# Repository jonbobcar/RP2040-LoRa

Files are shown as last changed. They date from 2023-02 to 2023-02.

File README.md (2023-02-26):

# RP2040 LoRa
 RP2040 based board with a LoRa radio

KiCad files are made with KiCad v7.

Care should be used when purchasing BMS to choose one that will auto-start. There are SKUs of this BMS that will only start if external power is provided and then removed. I have chosen AP9101CAK6-ANTRG1, which is an auto-start version.

This board is mostly tested. Files on `main` should be used with caution, you may need to do some debugging.

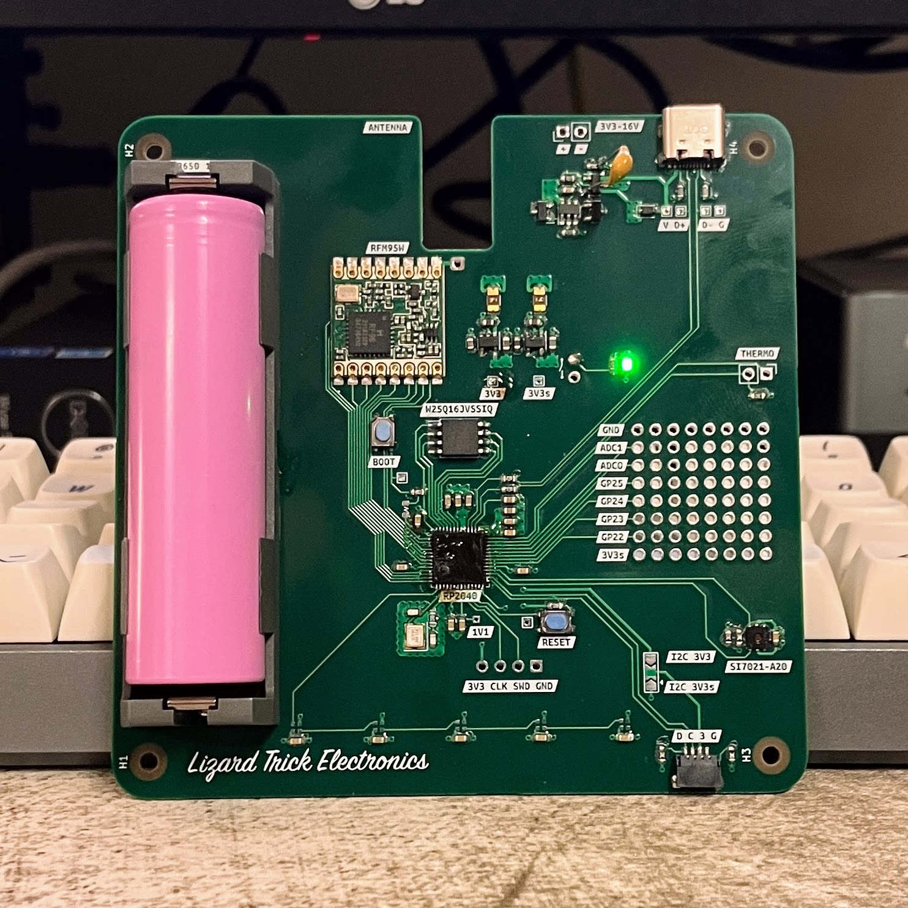
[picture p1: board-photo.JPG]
Photo of the board


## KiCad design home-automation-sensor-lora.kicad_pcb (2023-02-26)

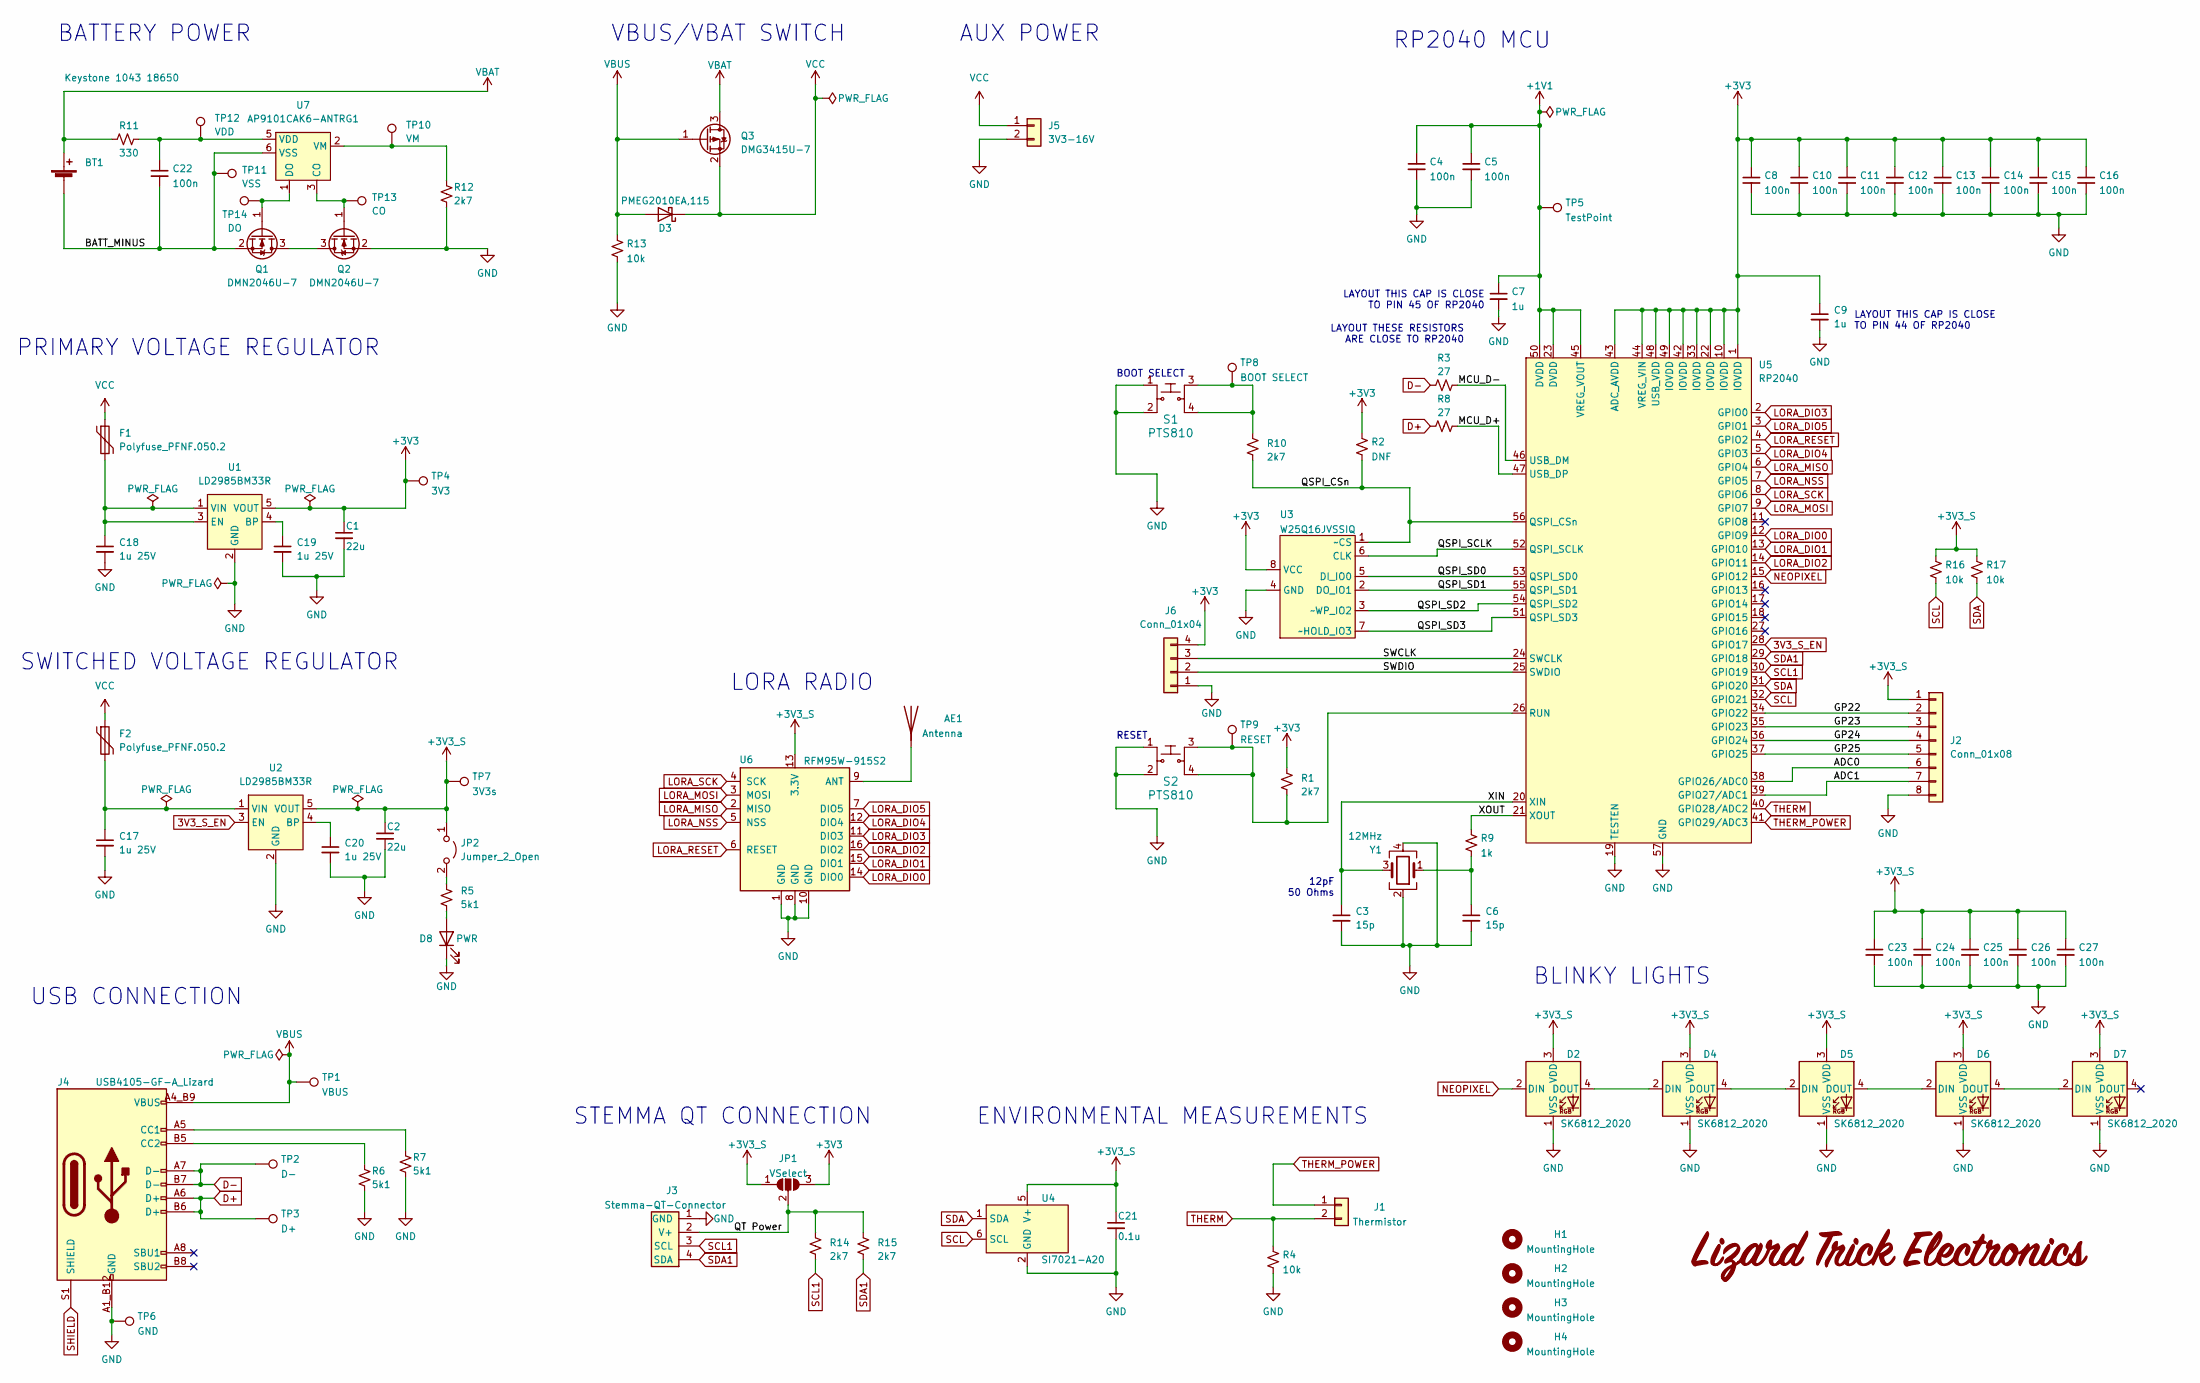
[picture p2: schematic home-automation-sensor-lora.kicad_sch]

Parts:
AE1: Antenna; Spring_Antenna_1.0_Drill
BT1: Keystone 1043 18650
C1, C2: 22u; C_0603_Lizard
C3, C6: 15p; C_0603_Lizard
C4, C5, C8, C10, C11, C12, C13, C14, C15, C16, C22, C23, C24, C25, C26, C27: 100n; C_0603_Lizard
C7, C9: 1u; C_0603_Lizard
C17, C18, C19, C20: 1u 25V; C_0603_Lizard
C21: 0.1u; C_0603_Lizard
D2, D4, D5, D6, D7: SK6812_2020; SK6812 2020
D3: PMEG2010EA,115; D_SOD-323
D8: PWR; LED-0805-Lizard
F1, F2: Polyfuse_PFNF.050.2; R_1206_3216Metric
G1: LOGO; Lizard Text Logo
H1, H2, H3, H4: MountingHole; Lizard_MountingHole_3.5mm
J1: Thermistor; PinHeader_1x02_P2.54mm_Vertical
J2: Conn_01x08; Prototype Area 8x8
J3: Stemma-QT-Connector; STEMMA-QT-CONNECTOR
J4: USB4105-GF-A_Lizard; GCT_USB4105-GF-A
J5: 3V3-16V; PinHeader_1x02_P2.54mm_Vertical
J6: Conn_01x04; PinHeader_1x04_P2.54mm_Vertical
JP1: VSelect; SolderJumper-3_P2.0mm_Open_TrianglePad1.0x1.5mm
JP2: Jumper_2_Open; Pin Jumper lizard
Q1, Q2: DMN2046U-7; SOT-23
Q3: DMG3415U-7; SOT-23
R1, R10, R12, R14, R15: 2k7; R_0603_Lizard
R2: DNF; R_0603_Lizard
R3, R8: 27; R_0603_Lizard
R4, R13, R16, R17: 10k; R_0603_Lizard
R5, R6, R7: 5k1; R_0603_Lizard
R9: 1k; R_0603_Lizard
R11: 330; R_0603_Lizard
S1, S2: PTS810; PTS_180_Tactile_Switch
TP1: VBUS; TestPoint_THTPad_1.0x1.0mm_Drill0.5mm
TP2: D-; TestPoint_THTPad_1.0x1.0mm_Drill0.5mm
TP3: D+; TestPoint_THTPad_1.0x1.0mm_Drill0.5mm
TP4: 3V3; TestPoint_THTPad_1.0x1.0mm_Drill0.5mm
TP5: TestPoint; TestPoint_THTPad_1.0x1.0mm_Drill0.5mm
TP6: GND; TestPoint_THTPad_1.0x1.0mm_Drill0.5mm
TP7: 3V3s; TestPoint_THTPad_1.0x1.0mm_Drill0.5mm
TP8: BOOT SELECT; TestPoint_THTPad_1.0x1.0mm_Drill0.5mm
TP9: RESET; TestPoint_THTPad_1.0x1.0mm_Drill0.5mm
TP10: VM; TestPoint_THTPad_1.0x1.0mm_Drill0.5mm-Lizard
TP11: VSS; TestPoint_THTPad_1.0x1.0mm_Drill0.5mm-Lizard
TP12: VDD; TestPoint_THTPad_1.0x1.0mm_Drill0.5mm-Lizard
TP13: CO; TestPoint_THTPad_1.0x1.0mm_Drill0.5mm-Lizard
TP14: DO; TestPoint_THTPad_1.0x1.0mm_Drill0.5mm-Lizard
U1, U2: LD2985BM33R; SOT-23-5
U3: W25Q16JVSSIQ; SOIC-8_5.275x5.275mm_P1.27mm
U4: SI7021-A20
U5: RP2040; RP2040_QFN-56
U6: RFM95W-915S2; XCVR_RFM95W-915S2
U7: AP9101CAK6-ANTRG1; SOT-23-6
Y1: 12MHz; Crystal_SMD_3225-4Pin_3.2x2.5mm

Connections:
3V3_S_EN: U2.3 (EN), U5.28 (GPIO17)
+1V1: C4.1, C5.1, C7.1, TP5.1, U5.23 (DVDD), U5.45 (VREG_VOUT), U5.50 (DVDD)
+3V3: C1.1, C8.1, C9.1, C10.1, C11.1, C12.1, C13.1, C14.1, C15.1, C16.1, J6.4, JP1.3 (B), R1.1, R2.1, TP4.1, U1.5 (VOUT), U3.8 (VCC), U5.1 (IOVDD), U5.10 (IOVDD), U5.22 (IOVDD), U5.33 (IOVDD), U5.42 (IOVDD), U5.43 (ADC_AVDD), U5.44 (VREG_VIN), U5.48 (USB_VDD), U5.49 (IOVDD)
+3V3_S: C2.1, C21.1, C23.1, C24.1, C25.1, C26.1, C27.1, D2.3 (VDD), D4.3 (VDD), D5.3 (VDD), D6.3 (VDD), D7.3 (VDD), J2.1, JP1.1 (A), JP2.1 (A), R16.1, R17.1, TP7.1, U2.5 (VOUT), U4.5 (V+), U6.13 (3.3V)
/ADC0: J2.6, U5.38 (GPIO26/ADC0)
/ADC1: J2.7, U5.39 (GPIO27/ADC1)
/BATT_MINUS: BT1.1 (-), C22.2, Q1.2 (S), TP11.1, U7.6 (VSS)
/GP22: J2.2, U5.34 (GPIO22)
/GP23: J2.3, U5.35 (GPIO23)
/GP24: J2.4, U5.36 (GPIO24)
/GP25: J2.5, U5.37 (GPIO25)
/MCU_D+: R8.2, U5.47 (USB_DP)
/MCU_D-: R3.2, U5.46 (USB_DM)
/QSPI_CSn: R2.2, R10.2, U3.1 (~CS), U5.56 (QSPI_CSn)
/QSPI_SCLK: U3.6 (CLK), U5.52 (QSPI_SCLK)
/QSPI_SD0: U3.5 (DI_IO0), U5.53 (QSPI_SD0)
/QSPI_SD1: U3.2 (DO_IO1), U5.55 (QSPI_SD1)
/QSPI_SD2: U3.3 (~WP_IO2), U5.54 (QSPI_SD2)
/QSPI_SD3: U3.7 (~HOLD_IO3), U5.51 (QSPI_SD3)
/QT Power: J3.2 (V+), JP1.2 (C), R14.1, R15.1
/SWCLK: J6.3, U5.24 (SWCLK)
/SWDIO: J6.2, U5.25 (SWDIO)
/XIN: C3.1, U5.20 (XIN), Y1.3
/XOUT: R9.1, U5.21 (XOUT)
D+: J4.A6 (D+), J4.B6 (D+), R8.1, TP3.1
D-: J4.A7 (D-), J4.B7 (D-), R3.1, TP2.1
GND: C1.2, C2.2, C3.2, C4.2, C5.2, C6.2, C7.2, C8.2, C9.2, C10.2, C11.2, C12.2, C13.2, C14.2, C15.2, C16.2, C17.2, C18.2, C19.2, C20.2, C21.2, C23.2, C24.2, C25.2, C26.2, C27.2, D2.1 (VSS), D4.1 (VSS), D5.1 (VSS), D6.1 (VSS), D7.1 (VSS), D8.1 (K), J2.8, J3.1 (GND), J4.A1_B12 (GND), J4.B1_A12 (GND), J5.2, J6.1, Q2.2 (S), R4.2, R6.2, R7.2, R12.2, R13.2, S1.1, S1.2, S2.1, S2.2, TP6.1, U1.2 (GND), U2.2 (GND), U3.4 (GND), U4.2 (GND), U5.19 (TESTEN), U5.57 (GND), U6.1 (GND), U6.8 (GND), U6.10 (GND), Y1.2, Y1.4
LORA_DIO0: U5.12 (GPIO9), U6.14 (DIO0)
LORA_DIO1: U5.13 (GPIO10), U6.15 (DIO1)
LORA_DIO2: U5.14 (GPIO11), U6.16 (DIO2)
LORA_DIO3: U5.2 (GPIO0), U6.11 (DIO3)
LORA_DIO4: U5.5 (GPIO3), U6.12 (DIO4)
LORA_DIO5: U5.3 (GPIO1), U6.7 (DIO5)
LORA_MISO: U5.6 (GPIO4), U6.2 (MISO)
LORA_MOSI: U5.9 (GPIO7), U6.3 (MOSI)
LORA_NSS: U5.7 (GPIO5), U6.5 (NSS)
LORA_RESET: U5.4 (GPIO2), U6.6 (RESET)
LORA_SCK: U5.8 (GPIO6), U6.4 (SCK)
NEOPIXEL: D2.2 (DIN), U5.15 (GPIO12)
unnamed: AE1.1 (A), U6.9 (ANT)
unnamed: C6.1, R9.2, Y1.1
unnamed: D2.4 (DOUT), D4.2 (DIN)
unnamed: D4.4 (DOUT), D5.2 (DIN)
unnamed: D5.4 (DOUT), D6.2 (DIN)
unnamed: D6.4 (DOUT), D7.2 (DIN)
unnamed: D8.2 (A), R5.2
unnamed: J4.A5 (CC1), R7.1
unnamed: J4.B5 (CC2), R6.1
unnamed: JP2.2 (B), R5.1
unnamed: Q1.3 (D), Q2.3 (D)
unnamed: Q1.1 (G), TP14.1, U7.1 (DO)
unnamed: Q2.1 (G), TP13.1, U7.3 (CO)
unnamed: R10.1, S1.3, S1.4, TP8.1
unnamed: C19.1, U1.4 (BP)
unnamed: C18.1, F1.2, U1.1 (VIN), U1.3 (EN)
unnamed: C20.1, U2.4 (BP)
unnamed: C17.1, F2.2, U2.1 (VIN)
unnamed: R1.2, S2.3, S2.4, TP9.1, U5.26 (RUN)
unnamed: C22.1, R11.1, TP12.1, U7.5 (VDD)
unnamed: R12.1, TP10.1, U7.2 (VM)
SCL: R16.2, U4.6 (SCL), U5.32 (GPIO21)
SCL1: J3.3 (SCL), R14.2, U5.30 (GPIO19)
SDA: R17.2, U4.1 (SDA), U5.31 (GPIO20)
SDA1: J3.4 (SDA), R15.2, U5.29 (GPIO18)
SHIELD: J4.S1 (SHIELD)
THERM: J1.2, R4.1, U5.40 (GPIO28/ADC2)
THERM_POWER: J1.1, U5.41 (GPIO29/ADC3)
VBUS: D3.2 (A), J4.A4_B9 (VBUS), J4.B4_A9 (VBUS), Q3.1 (G), R13.1, TP1.1
VCC: D3.1 (K), F1.1, F2.1, J5.1, Q3.2 (S)
VDD: BT1.2 (+), Q3.3 (D), R11.2

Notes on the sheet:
STEMMA QT CONNECTION
RESET
RP2040 MCU
LAYOUT THIS CAP IS CLOSE TO PIN 44 OF RP2040
12pF 50 Ohms
USB CONNECTION
LORA RADIO
AUX POWER
SWITCHED VOLTAGE REGULATOR
VBUS/VBAT SWITCH
LAYOUT THESE RESISTORS ARE CLOSE TO RP2040
LAYOUT THIS CAP IS CLOSE TO PIN 45 OF RP2040
BLINKY LIGHTS
BATTERY POWER
PRIMARY VOLTAGE REGULATOR
ENVIRONMENTAL MEASUREMENTS
BOOT SELECT

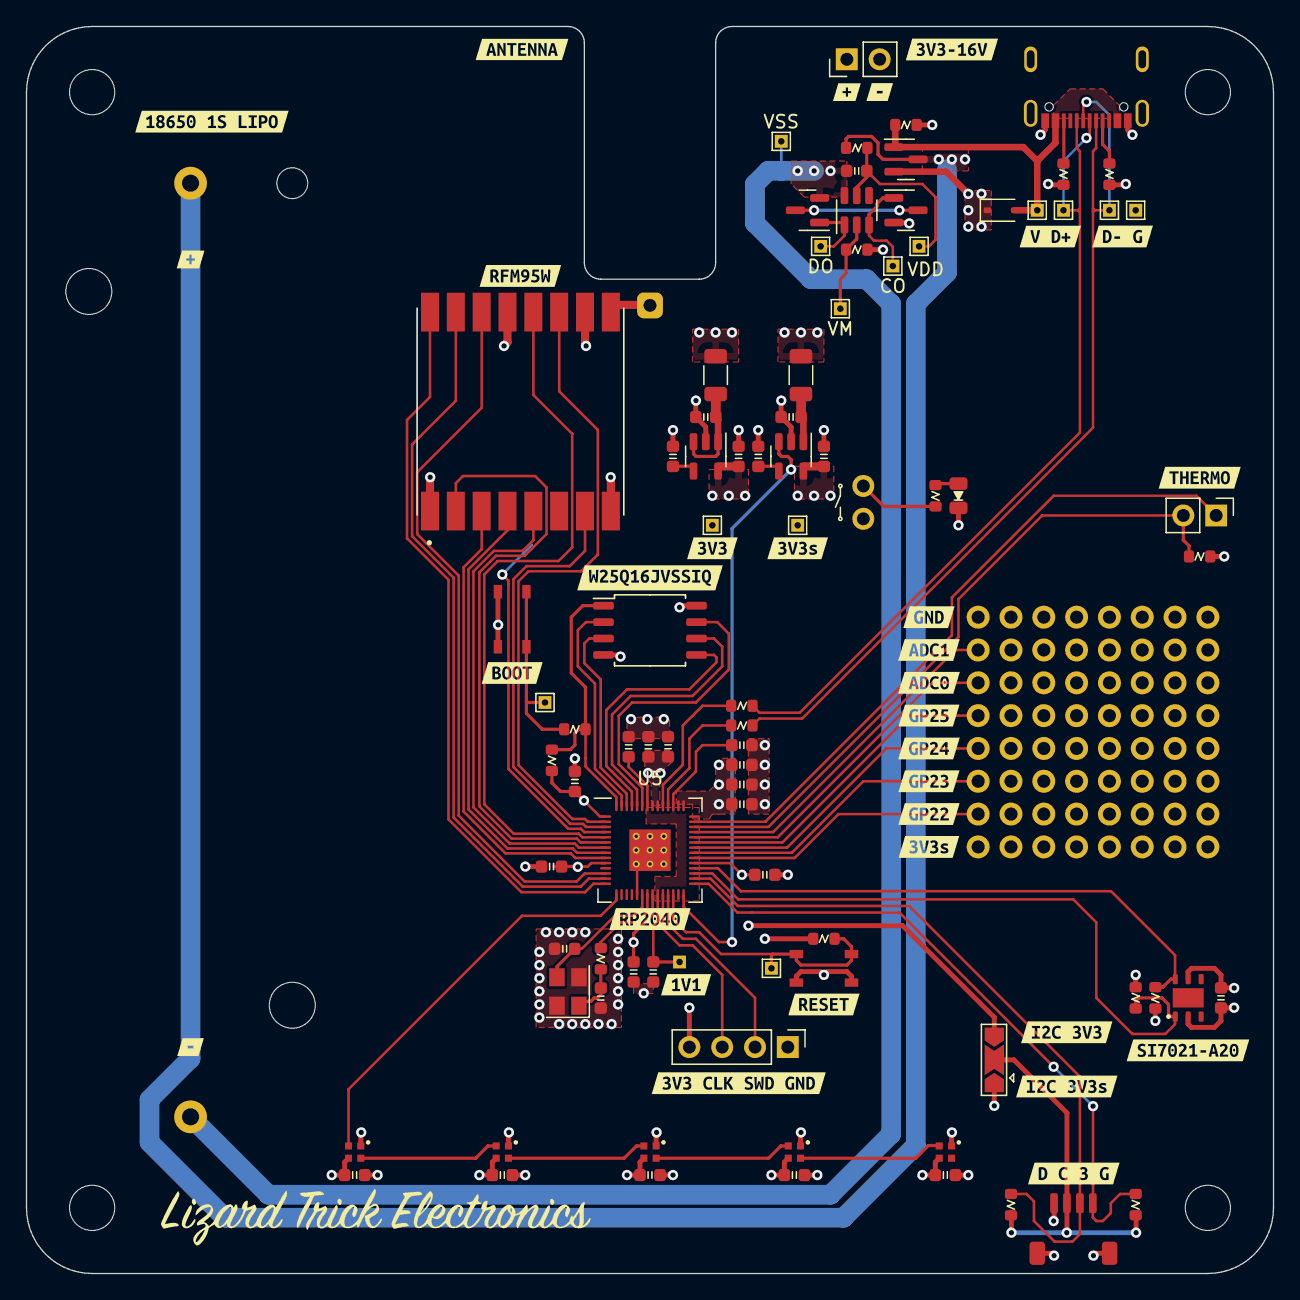
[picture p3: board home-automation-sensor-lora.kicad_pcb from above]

Board: 4 copper layers, 96.5 x 96.5 mm, 126 parts (1 on the bottom side), 69 nets.

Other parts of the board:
kibuzzard-63ABB0D8: G***; kibuzzard-63ABB0D8
kibuzzard-63ABB2C2: G***; kibuzzard-63ABB2C2
kibuzzard-63ABB2DA: G***; kibuzzard-63ABB2DA
kibuzzard-63ABB9BF: G***; kibuzzard-63ABB9BF
kibuzzard-63ABB33A: G***; kibuzzard-63ABB33A
kibuzzard-63ABB90E: G***; kibuzzard-63ABB90E
kibuzzard-63ABB100: G***; kibuzzard-63ABB100
kibuzzard-63ABB154: G***; kibuzzard-63ABB154
kibuzzard-63ABB174: G***; kibuzzard-63ABB174
kibuzzard-63ABB255: G***; kibuzzard-63ABB255
kibuzzard-63ABB925: G***; kibuzzard-63ABB925
kibuzzard-63ABBA8A, kibuzzard-63ABBA8A#2: G***; kibuzzard-63ABBA8A
kibuzzard-63ABBAAB, kibuzzard-63ABBAAB#2: G***; kibuzzard-63ABBAAB
kibuzzard-63ABCCDB: G***; kibuzzard-63ABCCDB
kibuzzard-63ABCCE2: G***; kibuzzard-63ABCCE2
kibuzzard-63ABCCEA: G***; kibuzzard-63ABCCEA
kibuzzard-63ABCCF2: G***; kibuzzard-63ABCCF2
kibuzzard-63ABCCF8: G***; kibuzzard-63ABCCF8
kibuzzard-63ABCCFF: G***; kibuzzard-63ABCCFF
kibuzzard-63ABCD0C: G***; kibuzzard-63ABCD0C
kibuzzard-63ABCD05: G***; kibuzzard-63ABCD05
kibuzzard-63ABCD13: G***; kibuzzard-63ABCD13
kibuzzard-63ABD5CF: G***; kibuzzard-63ABD5CF
kibuzzard-63ABD432: G***; kibuzzard-63ABD432
kibuzzard-63ABD482: G***; kibuzzard-63ABD482
kibuzzard-63ABD564: G***; kibuzzard-63ABD564
kibuzzard-63B9C3A5: G***; kibuzzard-63B9C3A5
kibuzzard-63B27CA9: G***; kibuzzard-63B27CA9
kibuzzard-63B32B21: G***; kibuzzard-63B32B21

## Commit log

2023-02-11 Initial commit of files
    [home-automation-sensor-lora-B_Cu.gbl, home-automation-sensor-lora-B_Mask.gbs, home-automation-sensor-lora-B_Paste.gbp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]
2023-02-11 Updated RP2040 footprint and updated routing to accommodate it
    [home-automation-sensor-lora.kicad_pcb, home-automation-sensor-lora.kicad_sch]
2023-02-12 Added test points to BMS chip.
    Tested BMS functionality and it is not working. It will prevent the battery from being charged at a high voltage, but it will not allow the battery to discharge under normal conditions. Interestingly, attaching 5V to VBUS or VCC while the battery is installed, then removing it, will "kick start" the BMS and allow discharging from the battery.
    [home-automation-sensor-lora-B_Cu.gbl, home-automation-sensor-lora-B_Mask.gbs, home-automation-sensor-lora-B_Paste.gbp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]
2023-02-12 added board photo
2023-02-12 Adjusted power planes around BMS
    [home-automation-sensor-lora.kicad_pcb, home-automation-sensor-lora.kicad_sch]
2023-02-13 finalized gerbers for production
    [home-automation-sensor-lora-B_Cu.gbl, home-automation-sensor-lora-B_Mask.gbs, home-automation-sensor-lora-B_Paste.gbp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]
2023-02-23 Moved LORA_MISO to GPIO4 and LORA_RESET to GPIO2
    [home-automation-sensor-lora.kicad_sch]
2023-02-26 updated silkscreen and footprints
    [home-automation-sensor-lora.kicad_pcb]
2023-02-26 corrected mirrored stemma qt connector pinout
    [home-automation-sensor-lora.kicad_pcb, home-automation-sensor-lora.kicad_sch]
2023-02-26 updated resistor values
    [home-automation-sensor-lora.kicad_sch]
2023-02-26 fixed routing to lora module
    [home-automation-sensor-lora.kicad_pcb]
2023-02-26 updated BMS to auto-start version
    [home-automation-sensor-lora.kicad_pcb, home-automation-sensor-lora.kicad_sch]
